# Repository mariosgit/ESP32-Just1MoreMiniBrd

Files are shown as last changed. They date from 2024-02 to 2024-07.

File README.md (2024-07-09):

# ESP32 minimal board

For use with one of these PRC Uart adapters...

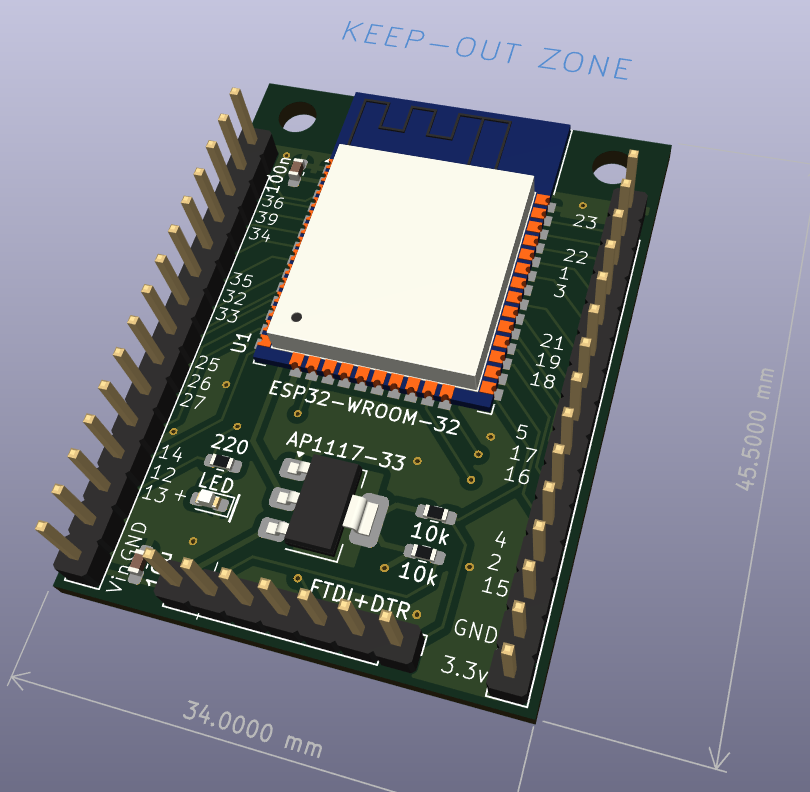
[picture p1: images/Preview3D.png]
preview


# Status

Working.

Gerber files do not show (all?) the footprint labels on silkscreen ?

# Usage

Plug the FTDI thing in the 6 right pins on the FTDI header.
Also make a connection from RTS on the FTDI adapter to the remaining left pin of the FTDI header. You can also connect 5V from the FTDI board to the Vin pin. Put the voltage select jumper on the FTDI board to 3.3V.

Now the ESP32 should get power (measure to the right of the FTDI header)
And it should be programmable from Arduino or PlatformIO.

The numbers on the outer pinheaders refere to the GPIO numbers.

realthing

# Ref

Inspired by  [this thing](https://electronoobs.com/eng_arduino_tut172.php)

# License

MIT

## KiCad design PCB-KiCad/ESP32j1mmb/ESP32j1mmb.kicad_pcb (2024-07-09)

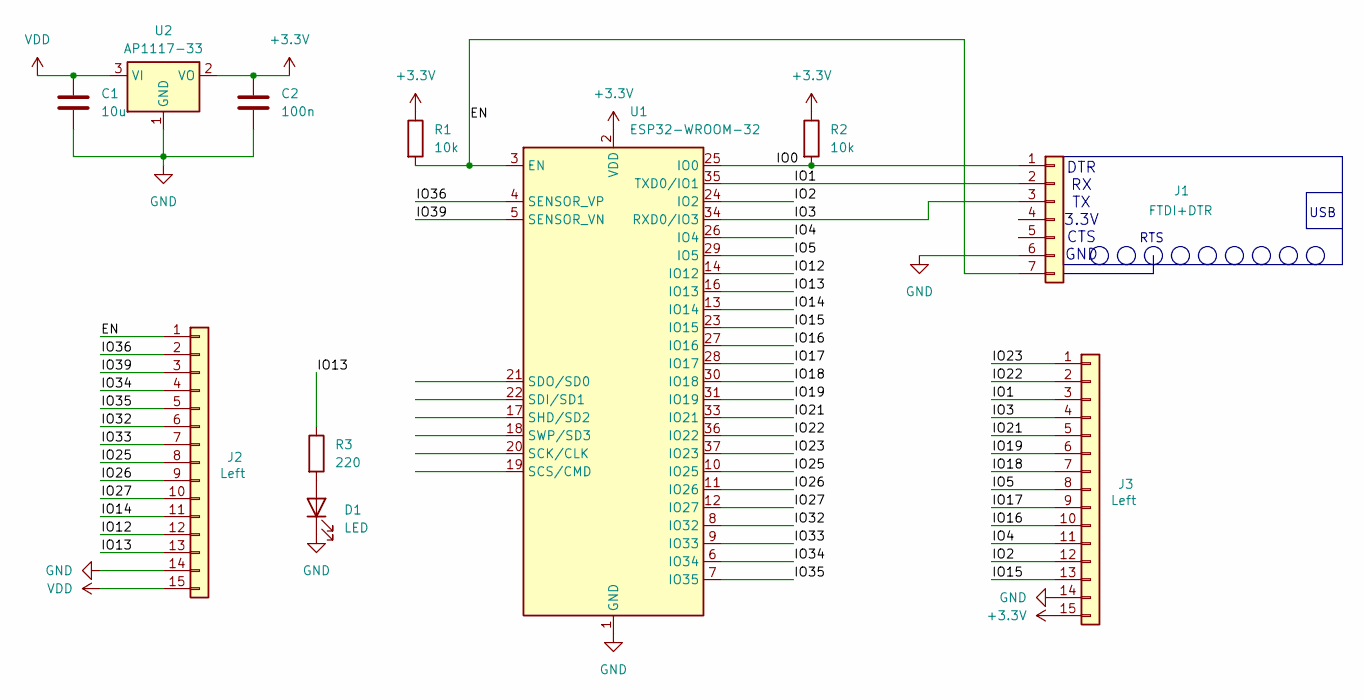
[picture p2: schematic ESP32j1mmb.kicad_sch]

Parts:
C1: 10u; C_0603_1608Metric_Pad1.08x0.95mm_HandSolder
C2: 100n; C_0603_1608Metric_Pad1.08x0.95mm_HandSolder
D1: LED; LED_0603_1608Metric_Pad1.05x0.95mm_HandSolder
J1: FTDI+DTR; PinHeader_1x07_P2.54mm_Vertical
J2, J3: Left; PinHeader_1x15_P2.54mm_Vertical
R1, R2: 10k; R_0603_1608Metric_Pad0.98x0.95mm_HandSolder
R3: 220; R_0603_1608Metric_Pad0.98x0.95mm_HandSolder
U1: ESP32-WROOM-32
U2: AP1117-33; SOT-223-3_TabPin2

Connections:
+3.3V: C2.1, J3.15, R1.1, R2.1, U1.2 (VDD), U2.2 (VO)
/EN: J1.7, J2.1, R1.2, U1.3 (EN)
/IO0: J1.1, R2.2, U1.25 (IO0)
/IO1: J1.2, J3.3, U1.35 (TXD0/IO1)
/IO2: J3.12, U1.24 (IO2)
/IO3: J1.3, J3.4, U1.34 (RXD0/IO3)
/IO4: J3.11, U1.26 (IO4)
/IO5: J3.8, U1.29 (IO5)
/IO12: J2.12, U1.14 (IO12)
/IO13: J2.13, R3.1, U1.16 (IO13)
/IO14: J2.11, U1.13 (IO14)
/IO15: J3.13, U1.23 (IO15)
/IO16: J3.10, U1.27 (IO16)
/IO17: J3.9, U1.28 (IO17)
/IO18: J3.7, U1.30 (IO18)
/IO19: J3.6, U1.31 (IO19)
/IO21: J3.5, U1.33 (IO21)
/IO22: J3.2, U1.36 (IO22)
/IO23: J3.1, U1.37 (IO23)
/IO25: J2.8, U1.10 (IO25)
/IO26: J2.9, U1.11 (IO26)
/IO27: J2.10, U1.12 (IO27)
/IO32: J2.6, U1.8 (IO32)
/IO33: J2.7, U1.9 (IO33)
/IO34: J2.4, U1.6 (IO34)
/IO35: J2.5, U1.7 (IO35)
/IO36: J2.2, U1.4 (SENSOR_VP)
/IO39: J2.3, U1.5 (SENSOR_VN)
GND: C1.2, C2.2, D1.1 (K), J1.6, J2.14, J3.14, U1.1 (GND), U1.15 (GND), U1.38 (GND), U1.39 (GND), U2.1 (GND)
unnamed: D1.2 (A), R3.2
VDD: C1.1, J2.15, U2.3 (VI)

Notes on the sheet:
USB
RTS
DTR RX TX 3.3V CTS GND

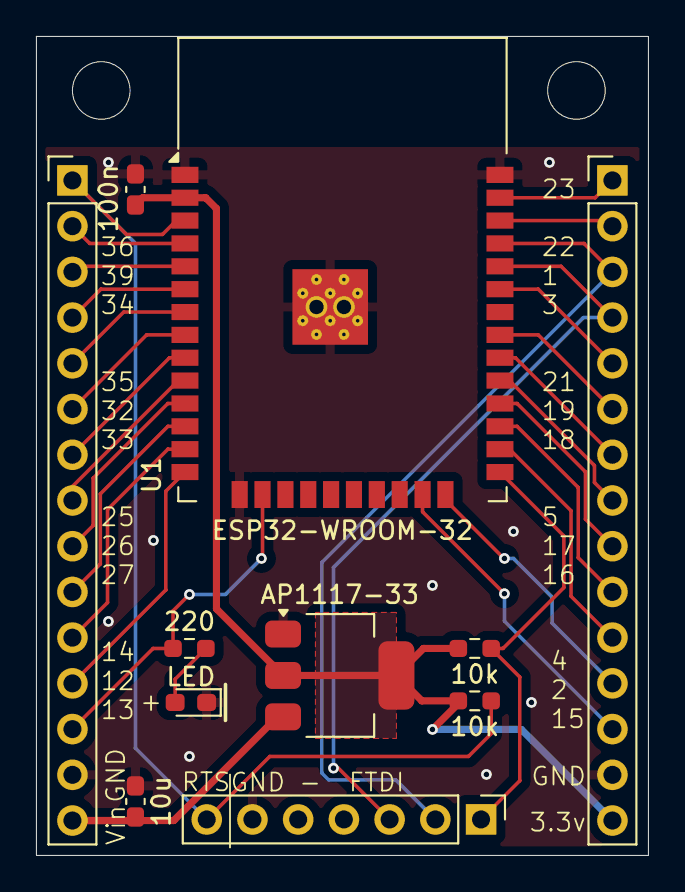
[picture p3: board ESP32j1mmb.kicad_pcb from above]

Board: 2 copper layers, 34.0 x 45.5 mm, 11 parts (0 on the bottom side), 31 nets.
